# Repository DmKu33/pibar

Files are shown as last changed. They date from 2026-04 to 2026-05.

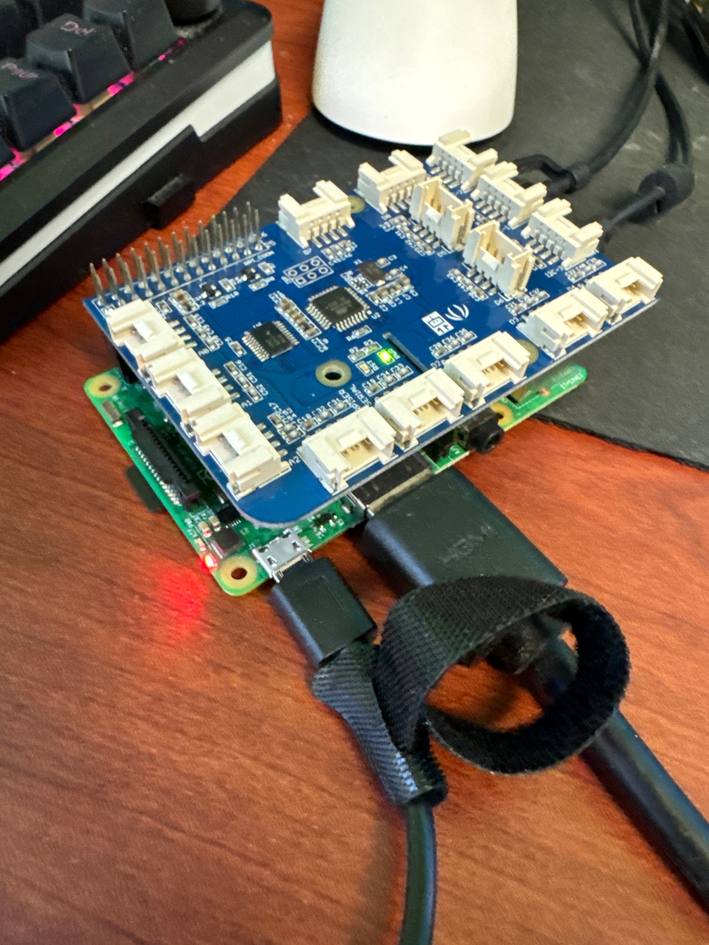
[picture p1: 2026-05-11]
pibar_imgs/grove_hat_home_setup.JPG

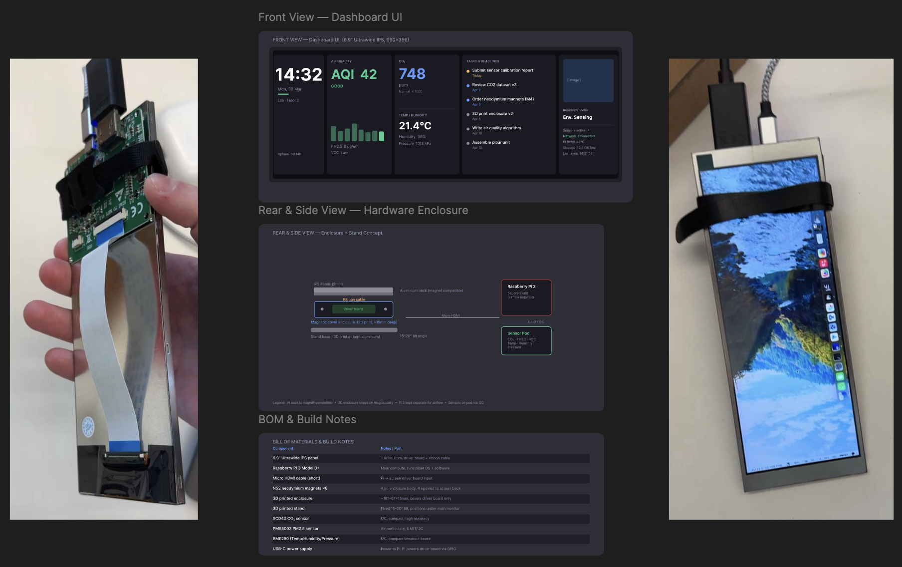
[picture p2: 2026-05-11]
pibar_imgs/dashboard_ui_ux_figma.png

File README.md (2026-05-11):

# pibar

Desk dashboard on a 6.9" 1280x480 ultrawide bar display driven by a Raspberry Pi 3. Sits under a main monitor. Shows room temperature, barometric pressure, reminders, and system stats. Reminders are added via Telegram bot.

## Stack

- Flask backend serving sensor data and tasks as JSON
- Single HTML page polled every 6s, rendered in Chromium kiosk mode
- BMP280 barometer via Grove Base Hat (I2C bus 1, addr 0x77)
- Telegram bot writes reminders to `tasks.md`

## Run

```bash
cp .env.example .env  # fill in TELEGRAM_TOKEN and TELEGRAM_OWNER_ID
bash run.sh
```

## Structure

```
backend/      Flask app, sensors, bot, tasks parser
frontend/     dashboard UI (single HTML file)
cad/          OpenSCAD enclosure model + STL exports
forge/        ForgeCAD enclosure (JavaScript + STL)
docs/         devlog and project documentation
pibar_imgs/   photos, screenshots, renders
```

## Hardware

- Raspberry Pi 3 Model B
- 6.9" 1280x480 IPS bar screen + HDMI-to-MIPI driver board
- Grove Base Hat for Raspberry Pi
- BMP280 barometer sensor

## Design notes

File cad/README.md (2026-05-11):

# pibar enclosure CAD draft

This folder contains a first-pass enclosure model for the current pibar concept:

- `pibar_enclosure.scad` — parametric source model
- `generate_enclosure_mesh.py` — pure-Python mesh exporter
- `out/` — generated `STL` and `OBJ` files for import into Tinkercad or other tools

## Current assumptions

This model is based on the latest dimensions you gave:

- screen overall size: `149.86 x 66.04 x 5.08 mm`
- Raspberry Pi 3: `85 x 56 x 17 mm`
- driver board: assumed `70 x 56 x 14 mm`
- mini breadboard: assumed `48 x 35 x 10 mm`

Important: the screen numbers are internally inconsistent with a true `6.9"` diagonal.

- `149.86 x 66.04 mm` works out to about `6.45"` diagonal
- earlier notes referenced roughly `181 x 67 mm`

So this is a **layout draft**, not a final print file. Before printing, update the screen values after measuring the real panel with calipers.

## Model intent

- two-part enclosure
  - `base tray`
  - `sliding lid`
- lid has:
  - front display window
  - screen-retention blocks behind the window
  - vent slots on one side
- base tray has:
  - internal cavity for Pi + driver board + mini breadboard
  - rear cable notch
  - front screw-post holes/bosses for adjustable feet

## Current outer size

- overall enclosure target: `205 x 45 x 84 mm`

Axis convention in the model:

- `X` = left to right across the long face
- `Y` = front to back depth
- `Z` = bottom to top height

## Files to import into Tinkercad

Use either:

- `out/pibar_base_tray.stl`
- `out/pibar_sliding_lid.stl`

or the matching `.obj` files.

`STL` is the safest target for Tinkercad import. `OBJ` is also included.

## Regenerate

Run:

```bash
python3 cad/generate_enclosure_mesh.py
```

## What still needs tuning

- exact screen outer size and visible area
- exact driver-board footprint and connector positions
- ribbon cable bend path
- whether the screw feet should be `M4` or `M5`
- whether the screw holes should stay printed as pilot holes or become full through-holes
- whether the vent pattern should move to the back instead of the side

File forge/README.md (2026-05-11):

# ForgeCAD enclosure model

This folder holds the first ForgeCAD version of the pibar enclosure.

Main file:

- `forge/pibar-enclosure.forge.js`

## What it models

- main enclosure body with:
  - front display window
  - top-access sliding lid
  - simple internal screen shelf and top capture bar
  - vents on both side walls
  - rear cable gap
- optional reference blocks for:
  - Raspberry Pi 3
  - HDMI driver board
  - mini breadboard
- underside front screw bosses / pilot holes for adjustable front feet

## Current assumptions

This draft uses your latest screen dimensions:

- width: `149.86 mm`
- height: `66.04 mm`
- thickness: `5.08 mm`

That does **not** match a true 6.9" diagonal, so treat this as a parametric fit study until you measure the real panel and visible area.

## Run

```bash
forgecad run forge/pibar-enclosure.forge.js
forgecad render 3d forge/pibar-enclosure.forge.js
forgecad render section forge/pibar-enclosure.forge.js --plane XZ
forgecad export stl forge/pibar-enclosure.forge.js
forgecad export step forge/pibar-enclosure.forge.js
```

## Parameters you will likely change first

- `Screen Width`
- `Screen Height`
- `Screen Thickness`
- `Driver Width`
- `Driver Height`
- `Driver Depth`
- `Enclosure Depth`
- `Foot Screw Pilot`
- `Lid Pullout`

## Suggested next validation loop

1. Run:

```bash
forgecad run forge/pibar-enclosure.forge.js
```

2. Then render:

```bash
forgecad render 3d forge/pibar-enclosure.forge.js
forgecad render section forge/pibar-enclosure.forge.js --plane XZ
```

3. If the body, lid, or screen fit look wrong, send me:
   - the `forgecad run` output
   - a screenshot or the rendered PNG

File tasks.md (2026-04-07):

# Tasks

- [ ] Submit sensor calibration report | 2026-04-07
- [ ] Review CO2 dataset v3 | 2026-04-08
- [ ] Order neodymium magnets | 2026-04-09
- [ ] 3D print enclosure v2 | 2026-04-12
- [ ] Write air quality algorithm | 2026-04-15
- [ ] Assemble pibar unit | 2026-04-20

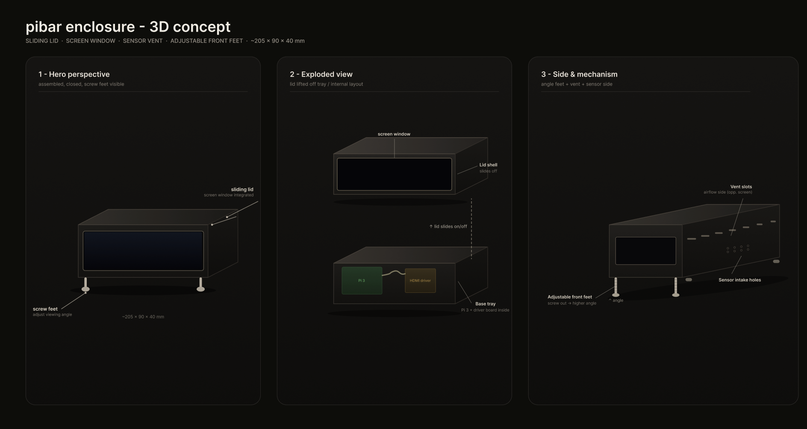
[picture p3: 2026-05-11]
pibar_imgs/figma_concept_enclosure_3d.png

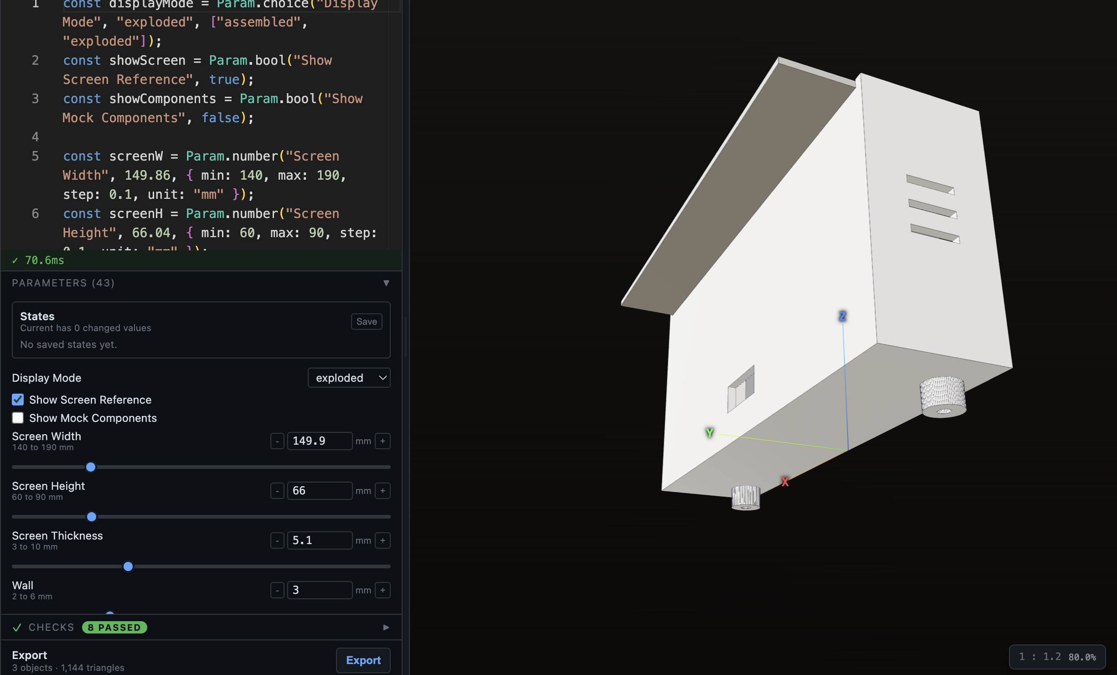
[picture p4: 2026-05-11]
pibar_imgs/enclosure_forgecad_back.png

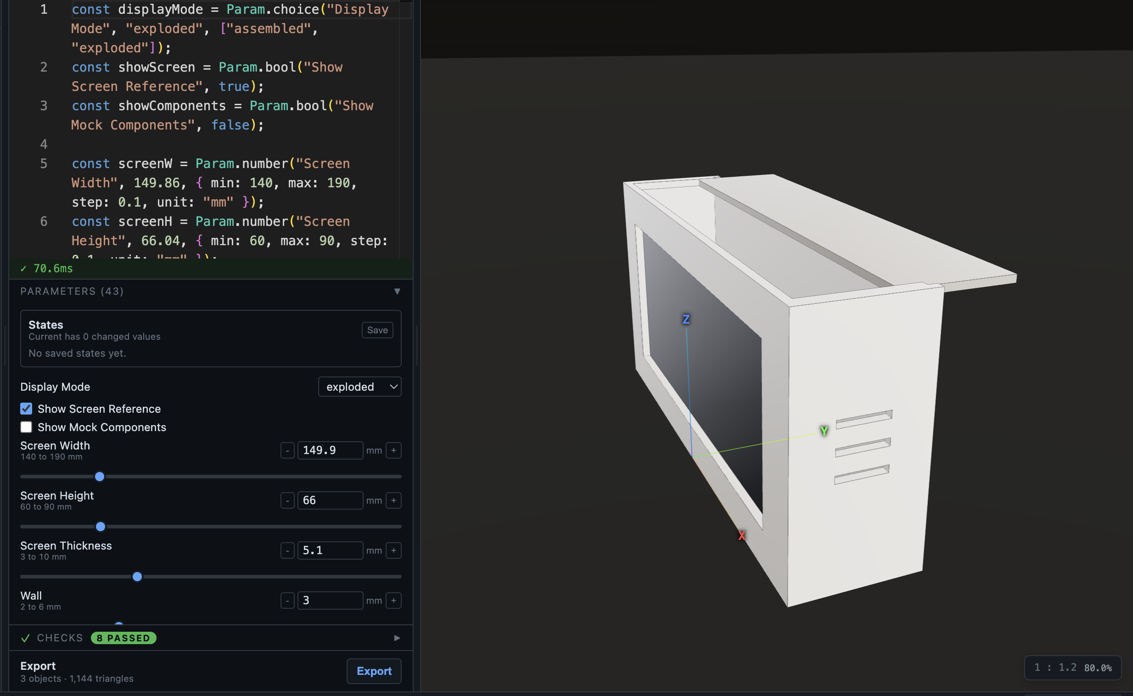
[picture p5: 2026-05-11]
pibar_imgs/enclosure_forgecad_front.png

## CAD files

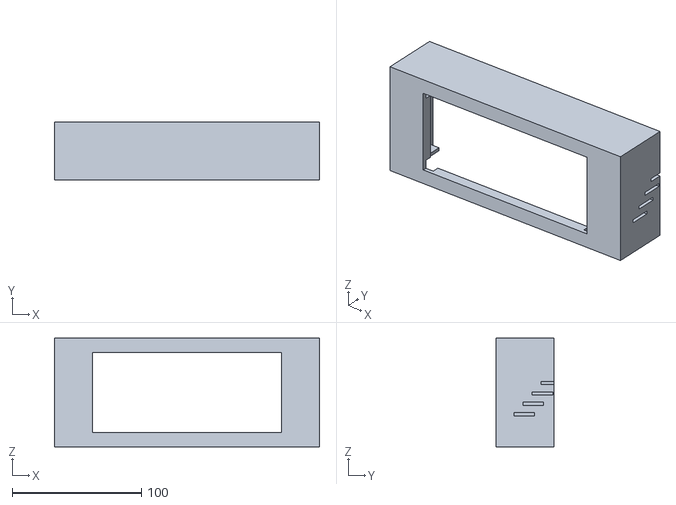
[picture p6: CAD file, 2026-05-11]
cad/out/pibar_sliding_lid.stl
205.0 x 45.0 x 84.0

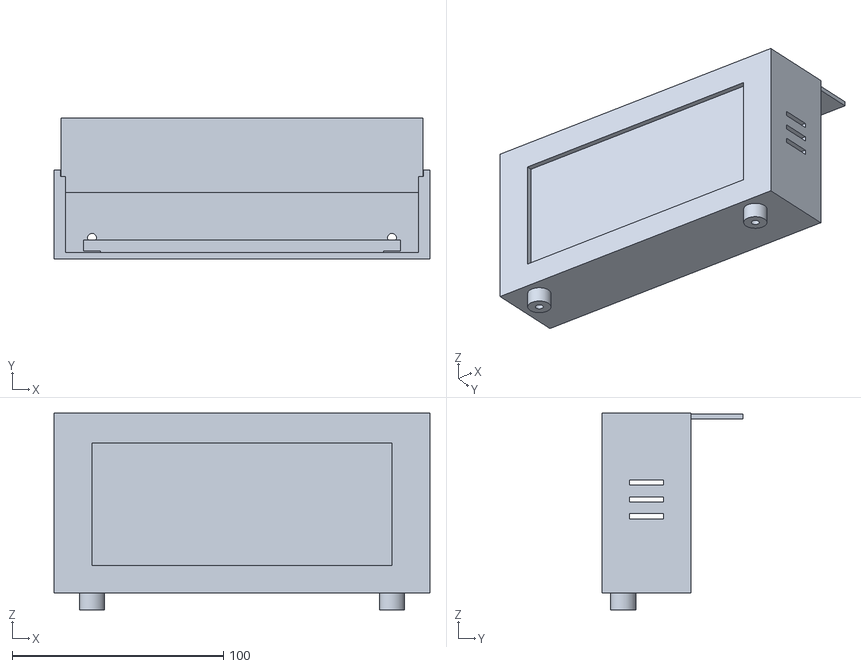
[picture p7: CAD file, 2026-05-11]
forge/v1.stl
177.9 x 66.7 x 93.0

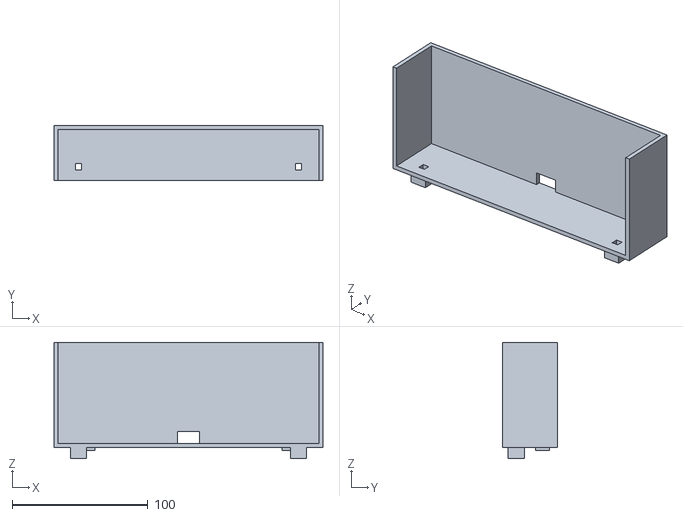
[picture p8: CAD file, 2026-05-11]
cad/out/pibar_base_tray.stl
197.8 x 40.4 x 85.4

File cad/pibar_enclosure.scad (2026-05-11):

// pibar enclosure - first-pass parametric concept
// Units: mm
//
// This file is meant for refinement and export to STL.
// Current screen numbers come from the latest message, but they conflict
// with the stated 6.9" diagonal. Re-measure the real panel before printing.

screen_outer_w = 149.86;
screen_outer_h = 66.04;
screen_t       = 5.08;

outer_w        = 205;
outer_d        = 45;
outer_h        = 84;

wall           = 3;
clearance      = 0.6;
runner_h       = 2.4;
runner_w       = 7;
face_t         = 3;
bottom_t       = 3;

window_w       = screen_outer_w - 4;
window_h       = screen_outer_h - 4;

tray_w         = outer_w - 2 * wall - 2 * clearance;
tray_d         = outer_d - face_t - clearance - 1.0;
tray_h         = outer_h - wall - runner_h - 2 * clearance;

pilot_hole     = 4.6;
pilot_outer    = 12;
pilot_depth    = 8;
pilot_offset_x = 18;
pilot_offset_y = 10;

retain_t       = 3;
retain_d       = 6;
retain_overlap = 1.5;
retain_margin  = 8;

vent_slot_w    = 16;
vent_slot_h    = 2.5;
vent_gap       = 7;

module base_tray() {
    difference() {
        union() {
            cube([tray_w, tray_d, bottom_t]);
            translate([0, 0, bottom_t])
                cube([wall, tray_d, tray_h - bottom_t]);
            translate([tray_w - wall, 0, bottom_t])
                cube([wall, tray_d, tray_h - bottom_t]);

            translate([0, tray_d - wall, bottom_t])
                difference() {
                    cube([tray_w, wall, tray_h - bottom_t]);
                    translate([(tray_w - 16) / 2, -0.1, 0])
                        cube([16, wall + 0.2, 12]);
                }

            translate([pilot_offset_x - pilot_outer / 2, pilot_offset_y - pilot_outer / 2, -pilot_depth])
                difference() {
                    cube([pilot_outer, pilot_outer, pilot_depth]);
                    translate([(pilot_outer - pilot_hole) / 2, (pilot_outer - pilot_hole) / 2, -0.1])
                        cube([pilot_hole, pilot_hole, pilot_depth + 0.2]);
                }

            translate([tray_w - pilot_offset_x - pilot_outer / 2, pilot_offset_y - pilot_outer / 2, -pilot_depth])
                difference() {
                    cube([pilot_outer, pilot_outer, pilot_depth]);
                    translate([(pilot_outer - pilot_hole) / 2, (pilot_outer - pilot_hole) / 2, -0.1])
                        cube([pilot_hole, pilot_hole, pilot_depth + 0.2]);
                }

            translate([18, tray_d - 16, -2])
                cube([12, 10, 2]);
            translate([tray_w - 30, tray_d - 16, -2])
                cube([12, 10, 2]);
        }

        translate([pilot_offset_x - pilot_hole / 2, pilot_offset_y - pilot_hole / 2, -0.1])
            cube([pilot_hole, pilot_hole, bottom_t + 0.2]);
        translate([tray_w - pilot_offset_x - pilot_hole / 2, pilot_offset_y - pilot_hole / 2, -0.1])
            cube([pilot_hole, pilot_hole, bottom_t + 0.2]);
    }
}

module sliding_lid() {
    screen_x0 = (outer_w - screen_outer_w) / 2;
    screen_z0 = (outer_h - screen_outer_h) / 2;
    window_x0 = (outer_w - window_w) / 2;
    window_z0 = (outer_h - window_h) / 2;

    difference() {
        union() {
            difference() {
                cube([outer_w, face_t, outer_h]);
                translate([window_x0, -0.1, window_z0])
                    cube([window_w, face_t + 0.2, window_h]);
            }

            translate([0, face_t, 0])
                cube([wall, outer_d - face_t, outer_h]);

            translate([outer_w - wall, face_t, 0])
                difference() {
                    cube([wall, outer_d - face_t, outer_h]);
                    for (i = [0:3]) {
                        translate([-0.1, 14 + i * vent_gap, 24 + i * 8])
                            cube([wall + 0.2, vent_slot_w, vent_slot_h]);
                    }
                }

            translate([0, face_t, outer_h - wall])
                cube([outer_w, outer_d - face_t, wall]);

            translate([wall, face_t, 0])
                cube([runner_w, outer_d - face_t - 2, runner_h]);

            translate([outer_w - wall - runner_w, face_t, 0])
                cube([runner_w, outer_d - face_t - 2, runner_h]);

            translate([screen_x0 - retain_t, face_t, screen_z0 + retain_margin])
                cube([retain_t + retain_overlap, retain_d, screen_outer_h - 2 * retain_margin]);

            translate([screen_x0 + screen_outer_w - retain_overlap, face_t, screen_z0 + retain_margin])
                cube([retain_t + retain_overlap, retain_d, screen_outer_h - 2 * retain_margin]);

            translate([screen_x0 + retain_margin, face_t, screen_z0 - retain_t])
                cube([screen_outer_w - 2 * retain_margin, retain_d, retain_t + retain_overlap]);

            translate([screen_x0 + retain_margin, face_t, screen_z0 + screen_outer_h - retain_overlap])
                cube([screen_outer_w - 2 * retain_margin, retain_d, retain_t + retain_overlap]);
        }
    }
}

// Uncomment one at a time for export:
// base_tray();
// sliding_lid();

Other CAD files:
cad/out/pibar_base_tray.obj
cad/out/pibar_sliding_lid.obj

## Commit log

2026-04-07 add sensor + system stats modules
2026-04-07 add task parser and sample tasks
2026-04-21 fix: use socket for IP detection instead of hostname -I
2026-05-11 fix: BMP280 sensor reads, responsive layout, cleanup fake AQI
2026-05-11 add: enclosure CAD files, OpenSCAD and ForgeCAD versions
    [pibar_base_tray.obj, pibar_base_tray.stl, pibar_enclosure.scad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]
2026-05-11 add: devlog, project images, enclosure renders
